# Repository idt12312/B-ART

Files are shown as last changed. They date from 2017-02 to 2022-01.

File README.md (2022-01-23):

# 概要
B-ARTはXbee ZigBeeモジュールみたいにUARTを無線で飛ばすモジュールです。
マイコンのプログラムを追加で書くことなく、UARTのTXとRXだけをつなげるだけでUARTを無線化できます。
無線部分はBLE(Bluetooth Low Energy)で実装をしています。

非常に小さいことが特徴で、**開発中の基板に挿して簡単に使える無線モジュール**をコンセプトに開発をしています。
(現状、秋月で買えるどの無線モジュールよりも小さいはず)

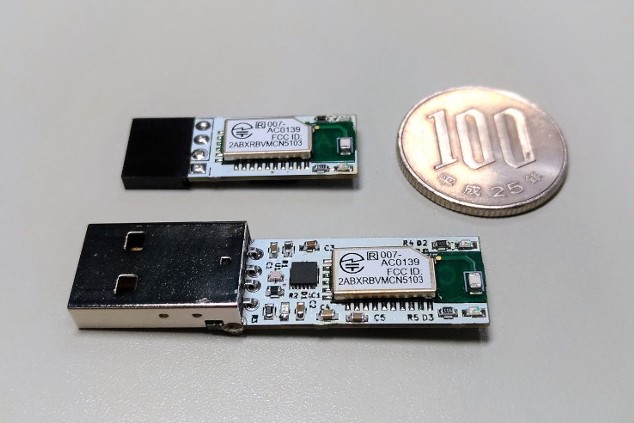
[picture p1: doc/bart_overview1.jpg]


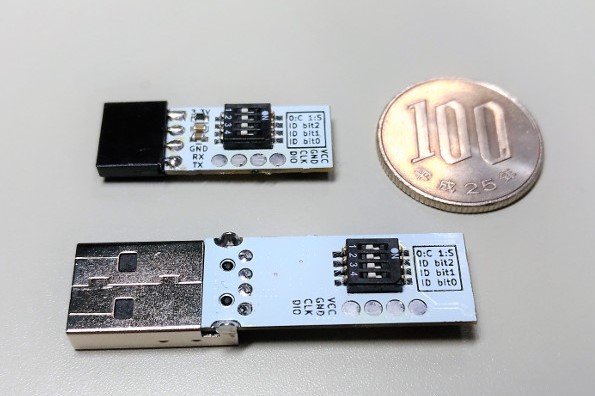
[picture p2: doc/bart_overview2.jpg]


B-ARTにはType-PとType-Uの2種類があり、Type-Pはピンヘッダ、Type-UはUSBコネクタがついています。
Type-Pには4pinのピンヘッダが付いていて、3.3V-GND-TX-RX
の4本を接続するだけで使うことができます。
Type-UにはPCに直接挿せるUSBコネクタと、FTDIのUSB-UART変換IC(FT234XD)が載っています。
FT234XDのおかげでPCにさすとシリアルポートとして認識されるので、
普段シリアルポートを使うときと全く変わることなく使うことができます。

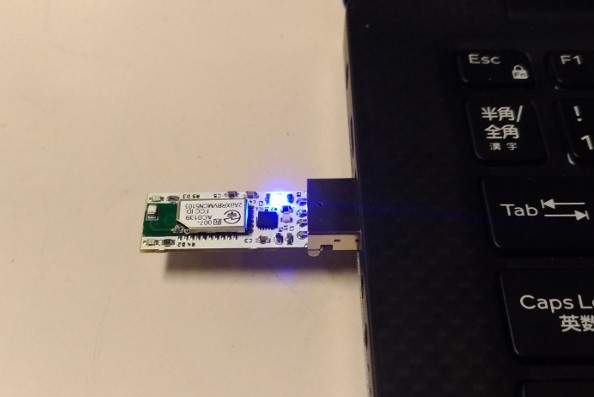
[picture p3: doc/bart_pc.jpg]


B-ARTの裏面にはType-P、Type-UともにDIPスイッチがあり、そこからIDを設定できます。
IDが同じ相手を選択して通信をするので、同じ環境にB-ARTが何組もあってもIDさえ違えば混線が起きないようになっています。

## 使用例
例えば小さい走行ロボットを無線を使ってデバッグする時にB-ARTは役立つでしょう。
走行をさせるときに有線だと線が邪魔になり、Xbeeなどはモジュールが大きすぎて載せられないという状況です。

下の写真は現在制作中のマイクロマウスの機体[MIZUHOv2](http://idken.net/posts/2017-04-01-mizuhov2/)に
B-ART TypePを挿しているところです。

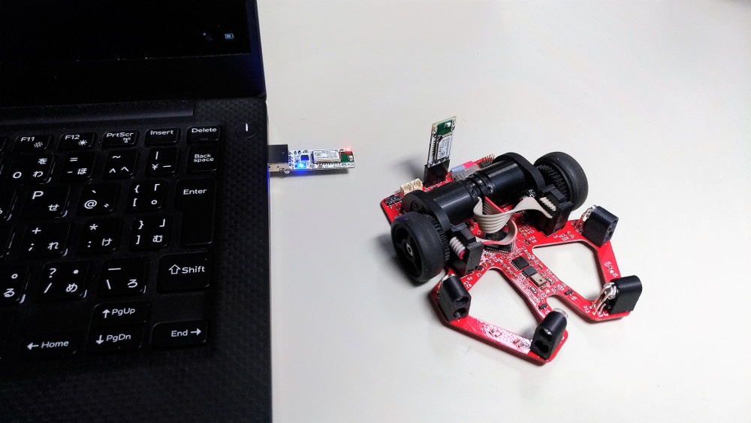
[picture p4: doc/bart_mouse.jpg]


B-ARTは非常に小さく軽いので、マイクロマウスの機体に乗せても走行時にそれほど問題にはなりません。
基板に4pinのコネクタさえつけておけばほしい時にだけB-ARTを挿して使うことができます。

# 使い方

## DIPスイッチの設定

B-ARTのType-PとType-Uの基板の裏にはDIPスイッチが4bit分あり、
1bitはクライアント動作をするかサーバー動作をするか、3bitはIDを意味していています。

| DIPスイッチ | 意味 |
|---|---|
| 1 | 0:client動作  1:server動作 |
| 2 | ID  bit2 |
| 3 | ID  bit1 |
| 4 | ID  bit0 |

B-ARTは通信においてはType-PであるかType-Uであるかは関係なく、
同じIDを持つサーバーとクライアントが1対1で通信できるという仕組みになっています。
なので、同じIDを持っていさえすれば、

* TypeU <-> TypeU
* TypeP <-> TypeP
* TypeU <-> TypeP

の全ての組み合わせで通信が可能です。

## TypePのセットアップ
4pinのピンヘッダ(というよりスルーホール)があり、それぞれのpinは次のような意味を持っています。

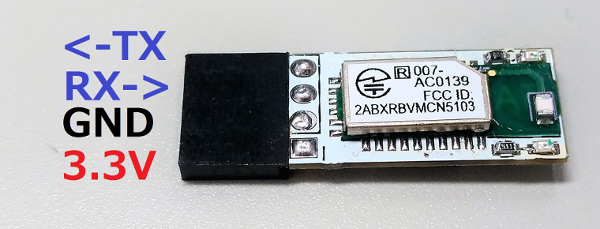
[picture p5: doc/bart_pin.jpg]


B-ARTは最大30mAくらいの電流を必要とするので、それに耐えられるような電源につないでください。

**電源・IOの電圧は3.3Vであることに注意してください**

## TypeUのセットアップ
パソコンのUSBに挿すだけです。

## 電源を入れる
電源を入れると
クライアント動作に設定されているB-ARTは赤色LEDが、
サーバー動作に設定されているB-ARTは緑色のLEDが光ります。

## サーバーとクライアントの接続
サーバー側とクライアント側に同じIDを持たせた状態で電源を入れると自動的に接続されます。
接続された瞬間にB-ARTに乗っている緑と赤の両方のLEDが一瞬点滅します。

一旦切断されても、接続可能な状態になると自動で接続されます。

## データを送受信する
UARTにデータを流すとサーバー側、クライアント側どちらからでももう片方に送信されます。
その際にLEDが点滅するので、LEDを見ることで正常に動作しているかが分かります。

### UARTの通信仕様

以下の設定でのみ動作します。

| パラメータ | 値 |
|---|---|
| Baudrate | 115200bps |
| Data size | 8bit |
| Start bit | 1bit |
| Stop bit | 1bit |
| Parity | なし |
| Flow control | なし |
| 信号レベル | 3.3V |

※UART側からデータを連続して送り続けると、データが欠損する可能性があります。
確実に連続して送信できるのは70byteくらいです。
それ以上のデータが連続する場合は、70byteくらいごとに間隔をあけてください。

# 基板

### TypeP

回路図

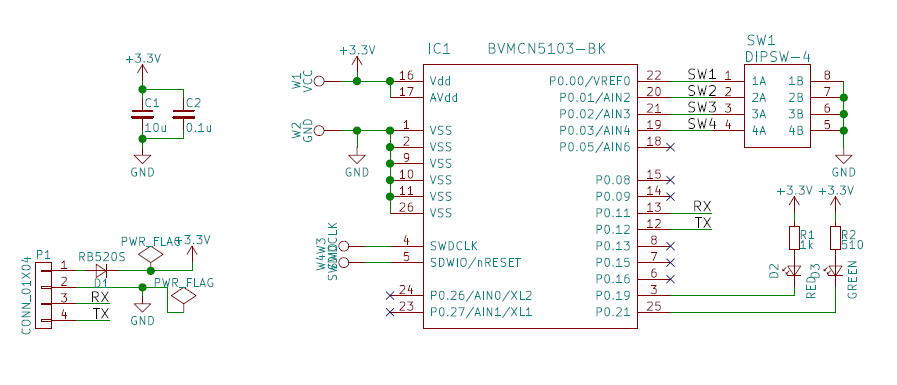
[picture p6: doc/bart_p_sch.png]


アートワーク

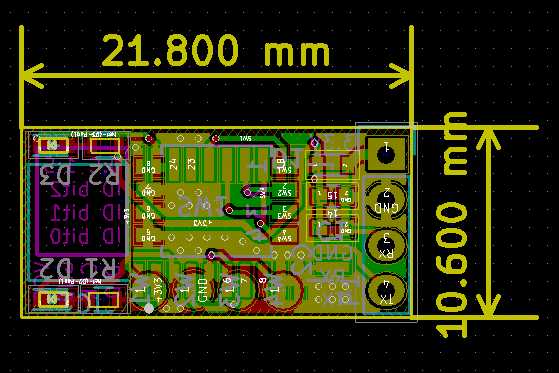
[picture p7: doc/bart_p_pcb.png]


### TypeU

USB周りの回路図

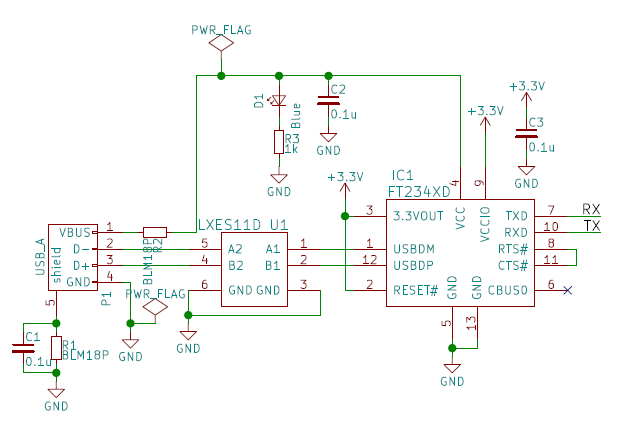
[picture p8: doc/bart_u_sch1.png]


マイコン周りの回路図

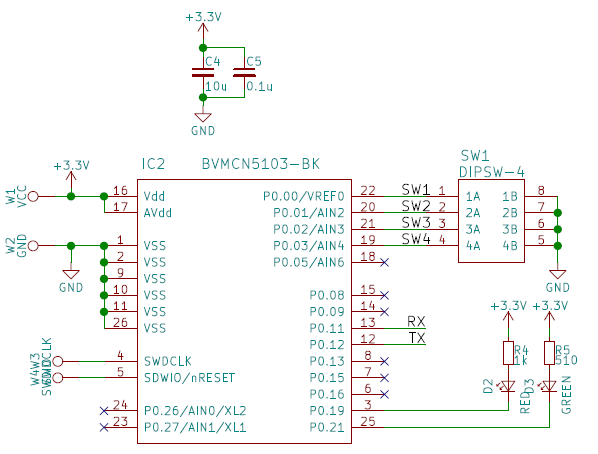
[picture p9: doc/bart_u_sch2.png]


アートワーク

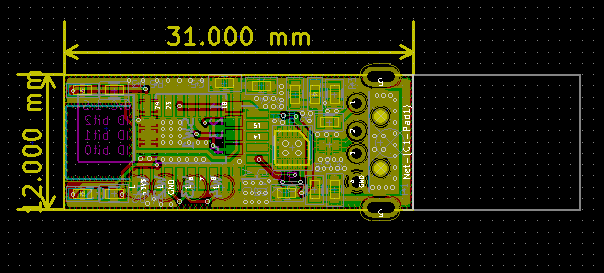
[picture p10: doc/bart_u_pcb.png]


# ファームウェア

## 最新のファームウェアのバイナリ

最新のビルドされたバイナリはbinディレクトリに入っています。

## 開発環境

* [Nordic nRF5 SDK v12.1](https://www.nordicsemi.com/eng/Products/Bluetooth-low-energy/nRF5-SDK)
* Nordic SoftDevice S130
* [Eclipse Juno](https://eclipse.org/)
* [Eclipse CDT](https://eclipse.org/cdt/)
* [GNU ARM Eclipse Plugin](http://gnuarmeclipse.github.io/)
* [gcc-arm-none-eabi-4_9-2015q3](https://launchpad.net/gcc-arm-embedded/4.9/4.9-2015-q3-update)

Eclipseのプロジェクトごとリポジトリにあげてあるので、
きっとEclipseにimportするだけで動かすことができます。

## 動作
起動時にDIPスイッチの状態を読み取って(main.c)、サーバー動作(main_server.c)をするか、
クライアント動作(main_client.c)をするかを決定しています。

BLEの操作はNordicのサンプルにある、NUSを参考にしています。
SDKにあるble_nusとble_nus_cをもとにble_bartsとble_barts_cを書いています。(名前を変えただけ)

### サーバー動作

GATTサーバーとして、次のようなサービスを立てます。

| AttributeType  | Name | Permissions | UUID |
|---|---|---|---|
| Service | BART Service | Read | 20yy0001-DA04-4C71-ADBE-6CA269E7E983 |
| Characteristic | TX | Write | 20yy0002-DA04-4C71-ADBE-6CA269E7E983 |
| Characteristic | RX | Notify | 20yy0003-DA04-4C71-ADBE-6CA269E7E983 |

TXにwriteするとUARTからデータが出力され、
UARTにデータが入るとRXをsubscribeしているデバイスにNotifyします。

UUIDのyyはID(3bit)を16進数に変換したものが入ります。

### クライアント動作
自分と同じIDをもつサーバーを探します。
このとき、サーバーのもつServiceのUUID(上の表のyy)をもとに同じIDのものを検索します。

同じIDのサーバーが見つかったらConnectし、RXのCharactericics(notify)をsubscribeします。

後はUARTからデータが来たらサーバーのRXにwriteをし、サーバーからnotifyが来たらUARTにデータを流します。

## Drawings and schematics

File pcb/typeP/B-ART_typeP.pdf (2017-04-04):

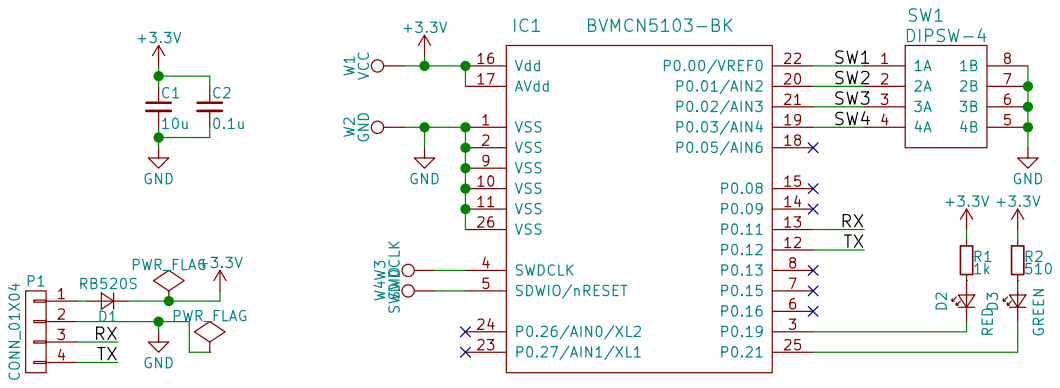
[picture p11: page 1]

SW4 W3 W4 SWDCLK SWDIO W1 VCC W2 GND

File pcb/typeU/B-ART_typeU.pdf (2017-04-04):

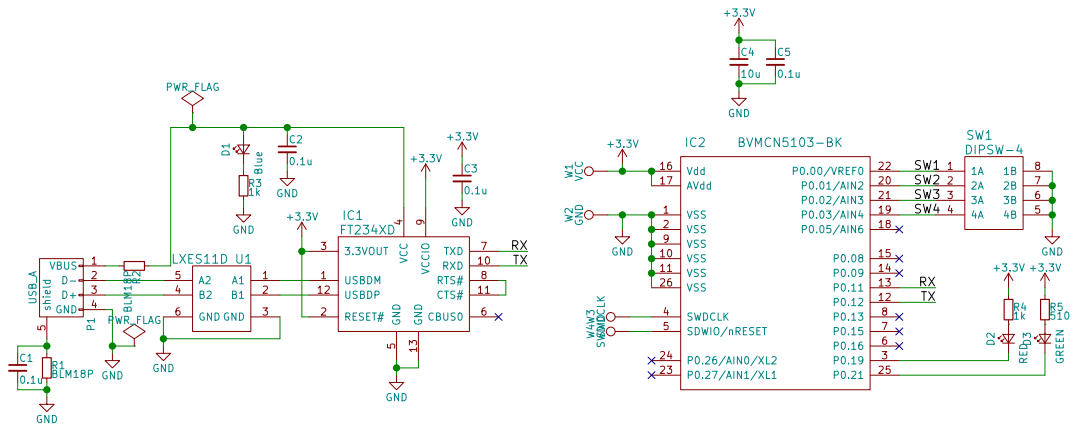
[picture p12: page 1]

9 RXD 10 CTS# 11 USBDP 12 GND 13

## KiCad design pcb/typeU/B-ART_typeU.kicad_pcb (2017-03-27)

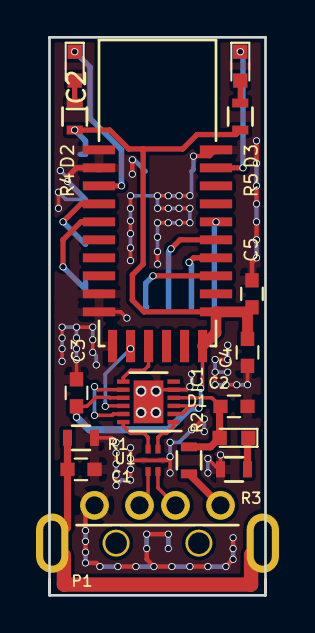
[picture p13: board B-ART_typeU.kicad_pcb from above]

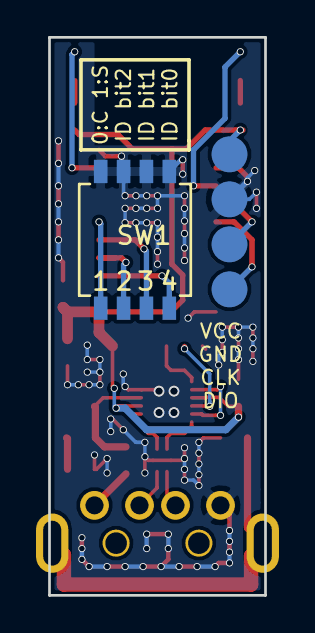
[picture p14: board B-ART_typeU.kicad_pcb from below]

Board: 2 copper layers, 12.0 x 31.0 mm, 22 parts (5 on the bottom side), 23 nets.

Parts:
C1, C2, C3, C5: 0.1u; C_0603
C4: 10u; C_0603
D1: Blue; LED_0603
D2: RED; LED_0603
D3: GREEN; LED_0603
IC1: FT234XD; DFN-12-1EP_3x3mm_Pitch0.45mm
IC2: BVMCN5103-BK
P1: USB_A; USB_A_plug
R1, R2: BLM18P; R_0603
R3, R4: 1k; R_0603
R5: 510; R_0603
SW1: DIPSW-4; DIPSW-4P
U1: LXES11D
W1: VCC; test_th_pad
W2: GND; test_th_pad
W3: SWDCLK; test_th_pad
W4: SWDIO; test_th_pad

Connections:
+3V3: C3.1, C4.1, C5.1, IC1.2, IC1.3, IC1.9, IC2.16, IC2.17, R4.1, R5.1, W1.1
/RX: IC1.7, IC2.13
/SW1: IC2.22, SW1.1
/SW2: IC2.20, SW1.2
/SW3: IC2.21, SW1.3
/SW4: IC2.19, SW1.4
/TX: IC1.10, IC2.12
GND: C1.2, C2.2, C3.2, C4.2, C5.2, IC1.5, IC1.13, IC2.1, IC2.2, IC2.9, IC2.10, IC2.11, IC2.26, P1.4, R1.2, R3.2, SW1.5, SW1.6, SW1.7, SW1.8, U1.3, U1.6, W2.1
unnamed: C1.1, P1.5, R1.1
unnamed: C2.1, D1.2, IC1.4, R2.1
unnamed: D1.1, R3.1
unnamed: D2.1, IC2.3
unnamed: D2.2, R4.2
unnamed: D3.1, IC2.25
unnamed: D3.2, R5.2
unnamed: IC1.1, U1.1
unnamed: IC1.8, IC1.11
unnamed: IC1.12, U1.2
unnamed: IC2.4, W3.1
unnamed: IC2.5, W4.1
unnamed: P1.1, R2.2
unnamed: P1.2, U1.5
unnamed: P1.3, U1.4

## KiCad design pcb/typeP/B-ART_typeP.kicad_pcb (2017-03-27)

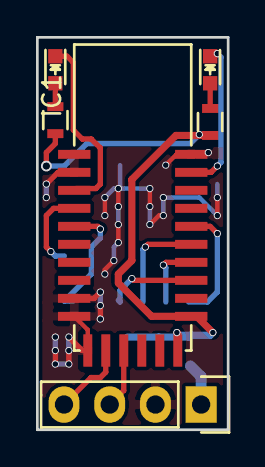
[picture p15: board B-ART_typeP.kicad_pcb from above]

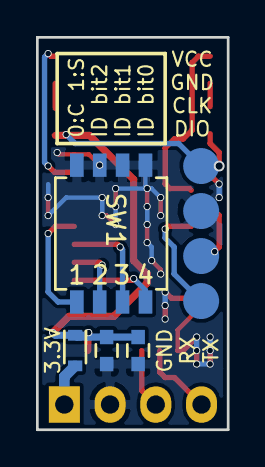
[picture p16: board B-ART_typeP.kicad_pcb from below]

Board: 2 copper layers, 10.6 x 21.8 mm, 14 parts (8 on the bottom side), 15 nets.

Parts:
C1: 10u; C_0603
C2: 0.1u; C_0603
D1: RB520S; D_0603
D2: RED; LED_0603
D3: GREEN; LED_0603
IC1: BVMCN5103-BK
P1: CONN_01X04; Pin_Header_Straight_1x04
R1: 1k; R_0603
R2: 510; R_0603
SW1: DIPSW-4; DIPSW-4P
W1: VCC; test_th_pad
W2: GND; test_th_pad
W3: SWDCLK; test_th_pad
W4: SWDIO; test_th_pad

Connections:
+3V3: C1.1, C2.1, D1.1, IC1.16, IC1.17, R1.1, R2.1, W1.1
/RX: IC1.13, P1.3
/SW1: IC1.22, SW1.1
/SW2: IC1.20, SW1.2
/SW3: IC1.21, SW1.3
/SW4: IC1.19, SW1.4
/TX: IC1.12, P1.4
GND: C1.2, C2.2, IC1.1, IC1.2, IC1.9, IC1.10, IC1.11, IC1.26, P1.2, SW1.5, SW1.6, SW1.7, SW1.8, W2.1
unnamed: D1.2, P1.1
unnamed: D2.1, IC1.3
unnamed: D2.2, R1.2
unnamed: D3.1, IC1.25
unnamed: D3.2, R2.2
unnamed: IC1.4, W3.1
unnamed: IC1.5, W4.1

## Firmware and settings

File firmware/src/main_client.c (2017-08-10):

#include <stdio.h>
#include <stdint.h>
#include <stdbool.h>
#include "nordic_common.h"
#include "app_error.h"
#include "app_uart.h"
#include "ble_db_discovery.h"
#include "app_timer.h"
#include "app_util.h"
#include "app_error.h"
#include "ble.h"
#include "ble_gap.h"
#include "ble_hci.h"
#include "softdevice_handler.h"
#include "ble_advdata.h"
#include "ble_barts_c.h"
#include "app_fifo.h"
#include "nrf_drv_clock.h"

#include "hardware_conf.h"
#include "led.h"


#ifdef DEBUG
#define DBG(...) printf(__VA_ARGS__)
#else
#define DBG(...)
#endif


#define CENTRAL_LINK_COUNT      1                               /**< Number of central links used by the application. When changing this number remember to adjust the RAM settings*/
#define PERIPHERAL_LINK_COUNT   0                               /**< Number of peripheral links used by the application. When changing this number remember to adjust the RAM settings*/

#define BARTS_SERVICE_UUID_TYPE   BLE_UUID_TYPE_VENDOR_BEGIN      /**< UUID type for the Nordic UART Service (vendor specific). */

#define SCAN_INTERVAL           0x00A0                          /**< Determines scan interval in units of 0.625 millisecond. */
#define SCAN_WINDOW             0x0050                          /**< Determines scan window in units of 0.625 millisecond. */
#define SCAN_ACTIVE             1                               /**< If 1, performe active scanning (scan requests). */
#define SCAN_SELECTIVE          0                               /**< If 1, ignore unknown devices (non whitelisted). */
#define SCAN_TIMEOUT            0x0000                          /**< Timout when scanning. 0x0000 disables timeout. */

#define MIN_CONNECTION_INTERVAL MSEC_TO_UNITS(7.5, UNIT_1_25_MS) /**< Determines minimum connection interval in millisecond. */
#define MAX_CONNECTION_INTERVAL MSEC_TO_UNITS(20, UNIT_1_25_MS) /**< Determines maximum connection interval in millisecond. */
#define SLAVE_LATENCY           0                               /**< Determines slave latency in counts of connection events. */
#define SUPERVISION_TIMEOUT     MSEC_TO_UNITS(4000, UNIT_10_MS) /**< Determines supervision time-out in units of 10 millisecond. */

#define UUID16_SIZE             2                               /**< Size of 16 bit UUID */
#define UUID32_SIZE             4                               /**< Size of 32 bit UUID */
#define UUID128_SIZE            16                              /**< Size of 128 bit UUID */

static ble_barts_c_t              m_ble_barts_c;                    /**< Instance of BARTS service. Must be passed to all BARTS_C API calls. */
static ble_db_discovery_t       m_ble_db_discovery;             /**< Instance of database discovery module. Must be passed to all db_discovert API calls */


static const ble_gap_conn_params_t m_connection_param =
{
		(uint16_t)MIN_CONNECTION_INTERVAL,  // Minimum connection
		(uint16_t)MAX_CONNECTION_INTERVAL,  // Maximum connection
		(uint16_t)SLAVE_LATENCY,            // Slave latency
		(uint16_t)SUPERVISION_TIMEOUT       // Supervision time-out
};

static const ble_gap_scan_params_t m_scan_params =
{
		.active      = SCAN_ACTIVE,
		.selective   = SCAN_SELECTIVE,
		.p_whitelist = NULL,
		.interval    = SCAN_INTERVAL,
		.window      = SCAN_WINDOW,
		.timeout     = SCAN_TIMEOUT
};

static const ble_uuid_t m_barts_uuid =
{
		.uuid = BLE_UUID_BARTS_SERVICE,
		.type = BARTS_SERVICE_UUID_TYPE
};


extern uint8_t uart_rcv_buff[UART_RCV_BUF_SIZE];
extern app_fifo_t uart_rcv_fifo;

static uint8_t ble_send_buf[20];
static uint32_t ble_to_send_size;
static bool is_remain_ble_to_send = false;
static bool is_ble_sending = false;
static bool is_ble_send_req = false;


static void transfer_data_from_uart_buf_to_ble()
{
	uint32_t err_code;

	while (1) {
		if (!is_remain_ble_to_send) {
			ble_to_send_size = 20;
			app_fifo_read(&uart_rcv_fifo, ble_send_buf, &ble_to_send_size);
			if (ble_to_send_size == 0) break;
		}

		DBG("[BLE send]");
		for (int i=0;i<ble_to_send_size;i++) {
			DBG("%02x",ble_send_buf[i]);
		}
		DBG("\n");

		err_code = ble_barts_c_send(&m_ble_barts_c, ble_send_buf, ble_to_send_size);

		if (err_code == NRF_SUCCESS) {
			DBG("[BLE send] success\n");
			is_remain_ble_to_send = false;
		}
		else if (err_code == BLE_ERROR_NO_TX_PACKETS || NRF_ERROR_BUSY) {
			DBG("[BLE send] buffer full\n");
			is_remain_ble_to_send = true;
			break;
		}
		else if (err_code != NRF_ERROR_INVALID_STATE) {
			is_remain_ble_to_send = true;
			APP_ERROR_CHECK(err_code);
			break;
		}
	}

}

static void scan_start(void)
{
	uint32_t err_code;

	err_code = sd_ble_gap_scan_start(&m_scan_params);
	APP_ERROR_CHECK(err_code);
}


static void db_disc_handler(ble_db_discovery_evt_t * p_evt)
{
	ble_barts_c_on_db_disc_evt(&m_ble_barts_c, p_evt);
}


void client_uart_event_handle(app_uart_evt_t * p_event)
{
	uint8_t rcv_data;

	switch (p_event->evt_type) {
	case APP_UART_DATA_READY:
		app_uart_get(&rcv_data);

		// 未接続時はデータを無視
		if (m_ble_barts_c.conn_handle == BLE_CONN_HANDLE_INVALID) break;

		app_fifo_put(&uart_rcv_fifo, rcv_data);

		if (!is_ble_sending) {
			is_ble_send_req = true;
		}

		break;

	case APP_UART_COMMUNICATION_ERROR:
		APP_ERROR_HANDLER(p_event->data.error_communication);
		break;

	case APP_UART_FIFO_ERROR:
		APP_ERROR_HANDLER(p_event->data.error_code);
		break;

	default:
		break;
	}
}


static void ble_barts_c_evt_handler(ble_barts_c_t * p_ble_barts_c, const ble_barts_c_evt_t * p_ble_barts_evt)
{
	uint32_t err_code;
	switch (p_ble_barts_evt->evt_type) {
	case BLE_BARTS_C_EVT_DISCOVERY_COMPLETE:
		err_code = ble_barts_c_handles_assign(p_ble_barts_c, p_ble_barts_evt->conn_handle, &p_ble_barts_evt->handles);
		APP_ERROR_CHECK(err_code);

		err_code = ble_barts_c_rx_notif_enable(p_ble_barts_c);
		APP_ERROR_CHECK(err_code);
		DBG("The device has the BART Service\n");
		break;

	case BLE_BARTS_C_EVT_BARTS_RX_EVT:
		DBG("[UART send]");
		led_blink(RX_LED);
		for (uint32_t i = 0; i < p_ble_barts_evt->data_len; i++) {
			DBG("%c", p_ble_barts_evt->p_data[i]);
			while(app_uart_put( p_ble_barts_evt->p_data[i]) != NRF_SUCCESS);
		}
		DBG("\n");
		break;

	case BLE_BARTS_C_EVT_DISCONNECTED:
		DBG("Disconnected\n");
		led_off(TX_LED);
		led_on(RX_LED);
		scan_start();
		break;
	}
}


static bool is_uuid_present(const ble_uuid_t *p_target_uuid,
		const ble_gap_evt_adv_report_t *p_adv_report)
{
	uint32_t err_code;
	uint32_t index = 0;
	uint8_t *p_data = (uint8_t *)p_adv_report->data;
	ble_uuid_t extracted_uuid;

	while (index < p_adv_report->dlen)
	{
		uint8_t field_length = p_data[index];
		uint8_t field_type   = p_data[index+1];

		if ( (field_type == BLE_GAP_AD_TYPE_16BIT_SERVICE_UUID_MORE_AVAILABLE)
				|| (field_type == BLE_GAP_AD_TYPE_16BIT_SERVICE_UUID_COMPLETE)
		)
		{
			for (uint32_t u_index = 0; u_index < (field_length/UUID16_SIZE); u_index++) {
				err_code = sd_ble_uuid_decode(  UUID16_SIZE,
						&p_data[u_index * UUID16_SIZE + index + 2],
						&extracted_uuid);
				if (err_code == NRF_SUCCESS)
				{
					if ((extracted_uuid.uuid == p_target_uuid->uuid)
							&& (extracted_uuid.type == p_target_uuid->type))
					{
						return true;
					}
				}
			}
		}

		else if ( (field_type == BLE_GAP_AD_TYPE_32BIT_SERVICE_UUID_MORE_AVAILABLE)
				|| (field_type == BLE_GAP_AD_TYPE_32BIT_SERVICE_UUID_COMPLETE)
		)
		{
			for (uint32_t u_index = 0; u_index < (field_length/UUID32_SIZE); u_index++) {
				err_code = sd_ble_uuid_decode(UUID16_SIZE,
						&p_data[u_index * UUID32_SIZE + index + 2],
						&extracted_uuid);
				if (err_code == NRF_SUCCESS)
				{
					if ((extracted_uuid.uuid == p_target_uuid->uuid)
							&& (extracted_uuid.type == p_target_uuid->type))
					{
						return true;
					}
				}
			}
		}

		else if ( (field_type == BLE_GAP_AD_TYPE_128BIT_SERVICE_UUID_MORE_AVAILABLE)
				|| (field_type == BLE_GAP_AD_TYPE_128BIT_SERVICE_UUID_COMPLETE)
		)
		{
			err_code = sd_ble_uuid_decode(UUID128_SIZE,
					&p_data[index + 2],
					&extracted_uuid);
			if (err_code == NRF_SUCCESS)
			{
				if ((extracted_uuid.uuid == p_target_uuid->uuid)
						&& (extracted_uuid.type == p_target_uuid->type))
				{
					return true;
				}
			}
		}
		index += field_length + 1;
	}
	return false;
}


static void on_ble_evt(ble_evt_t * p_ble_evt)
{
	uint32_t              err_code;
	uint8_t dummy;
	const ble_gap_evt_t * p_gap_evt = &p_ble_evt->evt.gap_evt;

	switch (p_ble_evt->header.evt_id) {
	case BLE_GAP_EVT_ADV_REPORT:
	{
		DBG("[BLE event] BLE_GAP_EVT_ADV_REPORT\n");

		const ble_gap_evt_adv_report_t * p_adv_report = &p_gap_evt->params.adv_report;

		if (is_uuid_present(&m_barts_uuid, p_adv_report))
		{

			err_code = sd_ble_gap_connect(&p_adv_report->peer_addr,
					&m_scan_params,
					&m_connection_param);

			if (err_code == NRF_SUCCESS)
			{
				// scan is automatically stopped by the connect
				APP_ERROR_CHECK(err_code);
				DBG("Connecting to target %02x%02x%02x%02x%02x%02x\n",
						p_adv_report->peer_addr.addr[0],
						p_adv_report->peer_addr.addr[1],
						p_adv_report->peer_addr.addr[2],
						p_adv_report->peer_addr.addr[3],
						p_adv_report->peer_addr.addr[4],
						p_adv_report->peer_addr.addr[5]
				);
			}
		}
		break;
	}

	case BLE_GAP_EVT_CONNECTED:
		DBG("[BLE event] BLE_GAP_EVT_CONNECTED\n");
		led_blink(TX_LED);
		led_blink(RX_LED);

		// start discovery of services. The BARTS Client waits for a discovery result
		err_code = ble_db_discovery_start(&m_ble_db_discovery, p_ble_evt->evt.gap_evt.conn_handle);
		APP_ERROR_CHECK(err_code);
		break;

	case BLE_GAP_EVT_TIMEOUT:
		DBG("[BLE event] BLE_GAP_EVT_TIMEOUT\n");
		if (p_gap_evt->params.timeout.src == BLE_GAP_TIMEOUT_SRC_SCAN) {
			DBG("Scan timed out\n");
			scan_start();
		}
		else if (p_gap_evt->params.timeout.src == BLE_GAP_TIMEOUT_SRC_CONN) {
			DBG("Connection Request timed out\n");
		}
		break;

	case BLE_GAP_EVT_SEC_PARAMS_REQUEST:
		DBG("[BLE event] BLE_GAP_EVT_SEC_PARAMS_REQUEST\n");
		// Pairing not supported
		err_code = sd_ble_gap_sec_params_reply(p_ble_evt->evt.gap_evt.conn_handle, BLE_GAP_SEC_STATUS_PAIRING_NOT_SUPP, NULL, NULL);
		APP_ERROR_CHECK(err_code);
		break;

	case BLE_GAP_EVT_CONN_PARAM_UPDATE_REQUEST:
		DBG("[BLE event] BLE_GAP_EVT_CONN_PARAM_UPDATE_REQUEST\n");
		// Accepting parameters requested by peer.
		err_code = sd_ble_gap_conn_param_update(p_gap_evt->conn_handle,
				&p_gap_evt->params.conn_param_update_request.conn_params);
		APP_ERROR_CHECK(err_code);
		break;

	case BLE_EVT_TX_COMPLETE:
		led_blink(TX_LED);
		// fifoにデータが残っている
		if (app_fifo_peek(&uart_rcv_fifo, 0, &dummy) == NRF_SUCCESS) {
			transfer_data_from_uart_buf_to_ble();
		}
		else {
			is_ble_sending = false;
		}
		break;

	default:
		break;
	}
}


static void ble_evt_dispatch(ble_evt_t * p_ble_evt)
{
	on_ble_evt(p_ble_evt);
    ble_db_discovery_on_ble_evt(&m_ble_db_discovery, p_ble_evt);
	ble_barts_c_on_ble_evt(&m_ble_barts_c,p_ble_evt);
}


static void ble_stack_init(void)
{
	uint32_t err_code;

	nrf_clock_lf_cfg_t clock_lf_cfg = NRF_CLOCK_LFCLKSRC;

	// Initialize the SoftDevice handler module.
	SOFTDEVICE_HANDLER_INIT(&clock_lf_cfg, NULL);

	ble_enable_params_t ble_enable_params;
	err_code = softdevice_enable_get_default_config(CENTRAL_LINK_COUNT,
			PERIPHERAL_LINK_COUNT,
			&ble_enable_params);
	APP_ERROR_CHECK(err_code);

	//Check the ram settings against the used number of links
	CHECK_RAM_START_ADDR(CENTRAL_LINK_COUNT,PERIPHERAL_LINK_COUNT);

	// 各Bandwidthの許容する接続数を設定
	ble_conn_bw_counts_t bw_counts = {
			.tx_counts = {.high_count=1, .mid_count=0, .low_count=0},
			.rx_counts = {.high_count=1, .mid_count=0, .low_count=0}
	};
	ble_enable_params.common_enable_params.p_conn_bw_counts = &bw_counts;

	// Enable BLE stack.
	err_code = softdevice_enable(&ble_enable_params);
	APP_ERROR_CHECK(err_code);

	// Bandwidthをhihgに設定
	ble_opt_t ble_opt;
	memset(&ble_opt, 0x00, sizeof(ble_opt));
	ble_opt.common_opt.conn_bw.conn_bw.conn_bw_tx = BLE_CONN_BW_HIGH;
	ble_opt.common_opt.conn_bw.conn_bw.conn_bw_rx = BLE_CONN_BW_HIGH;
	ble_opt.common_opt.conn_bw.role = BLE_GAP_ROLE_CENTRAL;

	err_code = sd_ble_opt_set(BLE_COMMON_OPT_CONN_BW, &ble_opt);
	APP_ERROR_CHECK(err_code);

	// Register with the SoftDevice handler module for BLE events.
	err_code = softdevice_ble_evt_handler_set(ble_evt_dispatch);
	APP_ERROR_CHECK(err_code);
}


static void services_init(uint8_t device_id)
{
	uint32_t         err_code;
	ble_barts_c_init_t barts_c_init_t;

	barts_c_init_t.evt_handler = ble_barts_c_evt_handler;

	barts_c_init_t.device_id = device_id;
	DBG("[barts] Device ID : %u\n", barts_c_init_t.device_id);

	err_code = ble_barts_c_init(&m_ble_barts_c, &barts_c_init_t);
	APP_ERROR_CHECK(err_code);
}

static void db_discovery_init(void)
{
	uint32_t err_code = ble_db_discovery_init(db_disc_handler);
	APP_ERROR_CHECK(err_code);
}

static void clock_init()
{
	// 外部のXTALを起動
	uint32_t err_code = nrf_drv_clock_init();
	APP_ERROR_CHECK(err_code);

	nrf_clock_hfclk_t clk_src = nrf_clock_hf_src_get();
	if (clk_src == NRF_CLOCK_HFCLK_LOW_ACCURACY) {
		DBG("NRF_CLOCK_HFCLK_LOW_ACCURACY\n");
	}
	else {
		DBG("NRF_CLOCK_HFCLK_HIGH_ACCURACY\n");
	}

	if (nrf_clock_hf_is_running(NRF_CLOCK_HFCLK_LOW_ACCURACY)) {
		DBG("LOW RUNNING\n");
	}

	if (nrf_clock_hf_is_running(NRF_CLOCK_HFCLK_HIGH_ACCURACY)) {
		DBG("HIGH RUNNING\n");
	}
}

void client_main(uint8_t device_id)
{
	uint32_t err_code;

	app_fifo_init(&uart_rcv_fifo, uart_rcv_buff, UART_RCV_BUF_SIZE);

	db_discovery_init();
	ble_stack_init();
	clock_init();
	services_init(device_id);

	// Start scanning for peripherals and initiate connection
	// with devices that advertise BARTS UUID.
	scan_start();
	DBG("Scan started\n");

	//送信強度を4dB(最大)に設定
	err_code = sd_ble_gap_tx_power_set(4);
	APP_ERROR_CHECK(err_code);

	led_off(TX_LED);
	led_on(RX_LED);

	while (1) {
		if (is_ble_send_req) {
			is_ble_send_req = false;
			transfer_data_from_uart_buf_to_ble();
			is_ble_sending = true;
		}
		uint32_t err_code = sd_app_evt_wait();
		APP_ERROR_CHECK(err_code);
	}
}

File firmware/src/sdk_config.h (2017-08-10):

#ifndef SDK_CONFIG_H
#define SDK_CONFIG_H
// <<< Use Configuration Wizard in Context Menu >>>\n
#ifdef USE_APP_CONFIG
#include "app_config.h"
#endif
// <h> nRF_BLE 

//==========================================================
// <q> BLE_ADVERTISING_ENABLED  - ble_advertising - Advertising module
 

#ifndef BLE_ADVERTISING_ENABLED
#define BLE_ADVERTISING_ENABLED 1
#endif

// <q> BLE_DTM_ENABLED  - ble_dtm - Module for testing RF/PHY using DTM commands
 

#ifndef BLE_DTM_ENABLED
#define BLE_DTM_ENABLED 0
#endif

// <q> BLE_RACP_ENABLED  - ble_racp - Record Access Control Point library
 

#ifndef BLE_RACP_ENABLED
#define BLE_RACP_ENABLED 0
#endif

// <q> NRF_BLE_QWR_ENABLED  - nrf_ble_qwr - Queued writes support module (prepare/execute write)
 

#ifndef NRF_BLE_QWR_ENABLED
#define NRF_BLE_QWR_ENABLED 0
#endif

// <q> PEER_MANAGER_ENABLED  - peer_manager - Peer Manager
 

#ifndef PEER_MANAGER_ENABLED
#define PEER_MANAGER_ENABLED 0
#endif

// </h> 
//==========================================================

// <h> nRF_BLE_Services 

//==========================================================
// <q> BLE_ANCS_C_ENABLED  - ble_ancs_c - Apple Notification Service Client
 

#ifndef BLE_ANCS_C_ENABLED
#define BLE_ANCS_C_ENABLED 0
#endif

// <q> BLE_ANS_C_ENABLED  - ble_ans_c - Alert Notification Service Client
 

#ifndef BLE_ANS_C_ENABLED
#define BLE_ANS_C_ENABLED 0
#endif

// <q> BLE_BAS_C_ENABLED  - ble_bas_c - Battery Service Client
 

#ifndef BLE_BAS_C_ENABLED
#define BLE_BAS_C_ENABLED 0
#endif

// <q> BLE_BAS_ENABLED  - ble_bas - Battery Service
 

#ifndef BLE_BAS_ENABLED
#define BLE_BAS_ENABLED 0
#endif

// <q> BLE_CSCS_ENABLED  - ble_cscs - Cycling Speed and Cadence Service
 

#ifndef BLE_CSCS_ENABLED
#define BLE_CSCS_ENABLED 0
#endif

// <q> BLE_CTS_C_ENABLED  - ble_cts_c - Current Time Service Client
 

#ifndef BLE_CTS_C_ENABLED
#define BLE_CTS_C_ENABLED 0
#endif

// <q> BLE_DIS_ENABLED  - ble_dis - Device Information Service
 

#ifndef BLE_DIS_ENABLED
#define BLE_DIS_ENABLED 0
#endif

// <q> BLE_GLS_ENABLED  - ble_gls - Glucose Service
 

#ifndef BLE_GLS_ENABLED
#define BLE_GLS_ENABLED 0
#endif

// <q> BLE_HIDS_ENABLED  - ble_hids - Human Interface Device Service
 

#ifndef BLE_HIDS_ENABLED
#define BLE_HIDS_ENABLED 0
#endif

// <q> BLE_HRS_C_ENABLED  - ble_hrs_c - Heart Rate Service Client
 

#ifndef BLE_HRS_C_ENABLED
#define BLE_HRS_C_ENABLED 0
#endif

// <q> BLE_HRS_ENABLED  - ble_hrs - Heart Rate Service
 

#ifndef BLE_HRS_ENABLED
#define BLE_HRS_ENABLED 0
#endif

// <q> BLE_HTS_ENABLED  - ble_hts - Health Thermometer Service
 

#ifndef BLE_HTS_ENABLED
#define BLE_HTS_ENABLED 0
#endif

// <q> BLE_IAS_C_ENABLED  - ble_ias_c - Immediate Alert Service Client
 

#ifndef BLE_IAS_C_ENABLED
#define BLE_IAS_C_ENABLED 0
#endif

// <q> BLE_IAS_ENABLED  - ble_ias - Immediate Alert Service
 

#ifndef BLE_IAS_ENABLED
#define BLE_IAS_ENABLED 0
#endif

// <q> BLE_LBS_C_ENABLED  - ble_lbs_c - Nordic LED Button Service Client
 

#ifndef BLE_LBS_C_ENABLED
#define BLE_LBS_C_ENABLED 0
#endif

// <q> BLE_LBS_ENABLED  - ble_lbs - LED Button Service
 

#ifndef BLE_LBS_ENABLED
#define BLE_LBS_ENABLED 0
#endif

// <q> BLE_LLS_ENABLED  - ble_lls - Link Loss Service
 

#ifndef BLE_LLS_ENABLED
#define BLE_LLS_ENABLED 0
#endif

// <q> BLE_NUS_C_ENABLED  - ble_nus_c - Nordic UART Central Service
 

#ifndef BLE_NUS_C_ENABLED
#define BLE_NUS_C_ENABLED 0
#endif

// <q> BLE_NUS_ENABLED  - ble_nus - Nordic UART Service
 

#ifndef BLE_NUS_ENABLED
#define BLE_NUS_ENABLED 0
#endif

// <q> BLE_RSCS_C_ENABLED  - ble_rscs_c - Running Speed and Cadence Client
 

#ifndef BLE_RSCS_C_ENABLED
#define BLE_RSCS_C_ENABLED 0
#endif

// <q> BLE_RSCS_ENABLED  - ble_rscs - Running Speed and Cadence Service
 

#ifndef BLE_RSCS_ENABLED
#define BLE_RSCS_ENABLED 0
#endif

// <q> BLE_TPS_ENABLED  - ble_tps - TX Power Service
 

#ifndef BLE_TPS_ENABLED
#define BLE_TPS_ENABLED 0
#endif

// </h> 
//==========================================================

// <h> nRF_Drivers 

//==========================================================
// <e> ADC_ENABLED - nrf_drv_adc - Driver for ADC peripheral (nRF51)
//==========================================================
#ifndef ADC_ENABLED
#define ADC_ENABLED 0
#endif
#if  ADC_ENABLED
// <o> ADC_CONFIG_IRQ_PRIORITY  - Interrupt priority
 

// <i> Priorities 0,2 (nRF51) and 0,1,4,5 (nRF52) are reserved for SoftDevice
// <0=> 0 (highest) 
// <1=> 1 
// <2=> 2 
// <3=> 3 

#ifndef ADC_CONFIG_IRQ_PRIORITY
#define ADC_CONFIG_IRQ_PRIORITY 3
#endif

#endif //ADC_ENABLED
// </e>

// <e> CLOCK_ENABLED - nrf_drv_clock - CLOCK peripheral driver
//==========================================================
#ifndef CLOCK_ENABLED
#define CLOCK_ENABLED 1
#endif
#if  CLOCK_ENABLED
// <o> CLOCK_CONFIG_XTAL_FREQ  - HF XTAL Frequency
 
// <0=> Default (64 MHz) 
// <255=> Default (16 MHz) 
// <0=> 32 MHz 

#ifndef CLOCK_CONFIG_XTAL_FREQ
#define CLOCK_CONFIG_XTAL_FREQ 255
#endif

// <o> CLOCK_CONFIG_LF_SRC  - LF Clock Source
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

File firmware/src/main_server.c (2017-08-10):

#include <stdint.h>
#include <string.h>
#include "nordic_common.h"
#include "nrf.h"
#include "ble_hci.h"
#include "ble_advdata.h"
#include "ble_advertising.h"
#include "ble_conn_params.h"
#include "softdevice_handler.h"
#include "app_timer.h"
#include "app_uart.h"
#include "app_util_platform.h"
#include "nrf_gpio.h"
#include "nrf_drv_clock.h"
#include "app_fifo.h"

#include "SEGGER_RTT.h"
#include "ble_barts.h"
#include "hardware_conf.h"
#include "led.h"


#ifdef DEBUG
#define DBG(...) printf(__VA_ARGS__)
#else
#define DBG(...)
#endif


#define APP_FEATURE_NOT_SUPPORTED       BLE_GATT_STATUS_ATTERR_APP_BEGIN + 2        /**< Reply when unsupported features are requested. */

#define CENTRAL_LINK_COUNT              0                                           /**< Number of central links used by the application. When changing this number remember to adjust the RAM settings*/
#define PERIPHERAL_LINK_COUNT           1                                           /**< Number of peripheral links used by the application. When changing this number remember to adjust the RAM settings*/

#define DEVICE_NAME                     "BART"                               /**< Name of device. Will be included in the advertising data. */
#define BARTS_SERVICE_UUID_TYPE           BLE_UUID_TYPE_VENDOR_BEGIN                  /**< UUID type for the Nordic UART Service (vendor specific). */

#define APP_ADV_INTERVAL                64                                          /**< The advertising interval (in units of 0.625 ms. This value corresponds to 100 ms). */
#define APP_ADV_TIMEOUT_IN_SECONDS      180                                         	/**< The advertising timeout (in units of seconds). */

#define MIN_CONN_INTERVAL               MSEC_TO_UNITS(7.5, UNIT_1_25_MS)             /**< Minimum acceptable connection interval (7.5 ms), Connection interval uses 1.25 ms units. */
#define MAX_CONN_INTERVAL               MSEC_TO_UNITS(20, UNIT_1_25_MS)             /**< Maximum acceptable connection interval (20 ms), Connection interval uses 1.25 ms units. */
#define SLAVE_LATENCY                   0                                           /**< Slave latency. */
#define CONN_SUP_TIMEOUT                MSEC_TO_UNITS(4000, UNIT_10_MS)             /**< Connection supervisory timeout (4 seconds), Supervision Timeout uses 10 ms units. */
#define FIRST_CONN_PARAMS_UPDATE_DELAY  APP_TIMER_TICKS(5000, APP_TIMER_PRESCALER)  /**< Time from initiating event (connect or start of notification) to first time sd_ble_gap_conn_param_update is called (5 seconds). */
#define NEXT_CONN_PARAMS_UPDATE_DELAY   APP_TIMER_TICKS(30000, APP_TIMER_PRESCALER) /**< Time between each call to sd_ble_gap_conn_param_update after the first call (30 seconds). */
#define MAX_CONN_PARAMS_UPDATE_COUNT    3                                           /**< Number of attempts before giving up the connection parameter negotiation. */

static ble_barts_t					m_barts;
static uint16_t                         m_conn_handle = BLE_CONN_HANDLE_INVALID;    /**< Handle of the current connection. */

static ble_uuid_t                       m_adv_uuids[] = {{.uuid = BLE_UUID_BARTS_SERVICE, .type = BARTS_SERVICE_UUID_TYPE}};


extern uint8_t uart_rcv_buff[UART_RCV_BUF_SIZE];
extern app_fifo_t uart_rcv_fifo;

static uint8_t ble_send_buf[20];
static uint32_t ble_to_send_size;
static bool is_remain_ble_to_send = false;
static bool is_ble_sending = false;
static bool is_ble_send_req = false;

static void transfer_data_from_uart_buf_to_ble()
{
	uint32_t err_code;

	while (1) {
		if (!is_remain_ble_to_send) {
			ble_to_send_size = 20;
			app_fifo_read(&uart_rcv_fifo, ble_send_buf, &ble_to_send_size);
			if (ble_to_send_size == 0) break;
		}

		DBG("[BLE send]");
		for (int i=0;i<ble_to_send_size;i++) {
			DBG("%02x",ble_send_buf[i]);
		}
		DBG("\n");

		err_code = ble_barts_send(&m_barts, ble_send_buf, ble_to_send_size);

		if (err_code == NRF_SUCCESS) {
			DBG("[BLE send] success\n");
			is_remain_ble_to_send = false;
		}
		else if (err_code == BLE_ERROR_NO_TX_PACKETS || NRF_ERROR_BUSY) {
			DBG("[BLE send] buffer full\n");
			is_remain_ble_to_send = true;
			break;
		}
		else if (err_code != NRF_ERROR_INVALID_STATE) {
			is_remain_ble_to_send = true;
			APP_ERROR_CHECK(err_code);
			break;
		}
	}

}

static void gap_params_init(void)
{
	uint32_t                err_code;
	ble_gap_conn_params_t   gap_conn_params;
	ble_gap_conn_sec_mode_t sec_mode;

	BLE_GAP_CONN_SEC_MODE_SET_OPEN(&sec_mode);

	err_code = sd_ble_gap_device_name_set(&sec_mode,
			(const uint8_t *) DEVICE_NAME,
			strlen(DEVICE_NAME));
	APP_ERROR_CHECK(err_code);

	memset(&gap_conn_params, 0, sizeof(gap_conn_params));

	gap_conn_params.min_conn_interval = MIN_CONN_INTERVAL;
	gap_conn_params.max_conn_interval = MAX_CONN_INTERVAL;
	gap_conn_params.slave_latency     = SLAVE_LATENCY;
	gap_conn_params.conn_sup_timeout  = CONN_SUP_TIMEOUT;

	err_code = sd_ble_gap_ppcp_set(&gap_conn_params);
	APP_ERROR_CHECK(err_code);
}


static void barts_data_handler(ble_barts_t * p_barts, uint8_t * p_data, uint16_t length)
{
	DBG("[UART send]");
	for (uint32_t i = 0; i < length; i++) {
		while (app_uart_put(p_data[i]) != NRF_SUCCESS);
		DBG("%c",p_data[i]);
	}
	DBG("\n");
}


static void services_init(uint8_t device_id)
{
	uint32_t       err_code;
	ble_barts_init_t barts_init;

	memset(&barts_init, 0, sizeof(barts_init));

	barts_init.data_handler = barts_data_handler;

	// device id の設定
	barts_init.device_id = device_id;
	DBG("[barts] Device ID : %u\n", barts_init.device_id);

	err_code = ble_barts_init(&m_barts, &barts_init);
	APP_ERROR_CHECK(err_code);
}


static void on_conn_params_evt(ble_conn_params_evt_t * p_evt)
{
	uint32_t err_code;

	if (p_evt->evt_type == BLE_CONN_PARAMS_EVT_FAILED) {
		err_code = sd_ble_gap_disconnect(m_conn_handle, BLE_HCI_CONN_INTERVAL_UNACCEPTABLE);
		APP_ERROR_CHECK(err_code);
	}
}


static void conn_params_error_handler(uint32_t nrf_error)
{
	APP_ERROR_HANDLER(nrf_error);
}


static void conn_params_init(void)
{
	uint32_t               err_code;
	ble_conn_params_init_t cp_init;

	memset(&cp_init, 0, sizeof(cp_init));

	cp_init.p_conn_params                  = NULL;
	cp_init.first_conn_params_update_delay = FIRST_CONN_PARAMS_UPDATE_DELAY;
	cp_init.next_conn_params_update_delay  = NEXT_CONN_PARAMS_UPDATE_DELAY;
	cp_init.max_conn_params_update_count   = MAX_CONN_PARAMS_UPDATE_COUNT;
	cp_init.start_on_notify_cccd_handle    = BLE_GATT_HANDLE_INVALID;
	cp_init.disconnect_on_fail             = false;
	cp_init.evt_handler                    = on_conn_params_evt;
	cp_init.error_handler                  = conn_params_error_handler;

	err_code = ble_conn_params_init(&cp_init);
	APP_ERROR_CHECK(err_code);
}
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

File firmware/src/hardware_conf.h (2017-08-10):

/*
 * hardware_conf.h
 *
 *  Created on: 2016/11/29
 *      Author: idt12312
 */

#ifndef SRC_HARDWARE_CONF_H_
#define SRC_HARDWARE_CONF_H_

#define TX_LED_PIN_NUMBER	21
#define RX_LED_PIN_NUMBER	19

#define	TX_PIN_NUMBER	12
#define	RX_PIN_NUMBER	11
#define	RTS_PIN_NUMBER	0
#define	CTS_PIN_NUMBER	0

#define DEVICEID_BIT0_PIN_NUMBER 3
#define DEVICEID_BIT1_PIN_NUMBER 2
#define DEVICEID_BIT2_PIN_NUMBER 1
#define DEVICE_MODE_PIN_NUMBER 0


#define UART_TX_BUF_SIZE                128                                         /**< UART TX buffer size. */
#define UART_RX_BUF_SIZE                64                                         /**< UART RX buffer size. */
#define UART_RCV_BUF_SIZE				128

/**< Value of the RTC1 PRESCALER register. */
#define APP_TIMER_PRESCALER 0

#define APP_TIMER_OP_QUEUE_SIZE         5                                           /**< Size of timer operation queues. */


#define NRF_CLOCK_LFCLKSRC      {.source        = NRF_CLOCK_LF_SRC_RC,            \
                                 .rc_ctiv       = 32,                                \
                                 .rc_temp_ctiv  = 1,                                \
                                 .xtal_accuracy = NRF_CLOCK_LF_XTAL_ACCURACY_250_PPM}



#endif /* SRC_HARDWARE_CONF_H_ */

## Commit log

2016-11-27 基板データを作成
    [uart2ble_bridge.kicad_pcb, uart2ble_bridge.sch]
2016-11-28 nordic SDK v12.1 + Eclipse で開発環境を構築 uart2bleのサービスを実装(nusとほとんど同じ)
2016-11-28 図面のプロパティを設定
    [uart2ble_bridge.kicad_pcb, uart2ble_bridge.sch]
2016-11-29 LEDを二つともマイコンから操作できるように変更
    [uart2ble_bridge.kicad_pcb, uart2ble_bridge.sch]
2016-11-29 LEDの操作を追加
2016-12-27 firm 裏面のジャンパーピンを参照してdevice idを決定する部分を実装
2016-12-27 firm LEDの光りかたを微調整
2017-01-15 アドバタイズに含めるserviceのUUIDを修正
2017-01-25 クライアントの処理を追加
    NUS_Cのサンプルを模倣
2017-01-29 クライアント側でBLEのイベントをdb_discoveryに通知し忘れていたので修正
2017-01-29 送信強度を4dB(最大)に設定
2017-01-29 LED, デバッグ出力周りを修正
2017-02-09 USB付き基板を追加 + 以前の基板も修正
    [uart2ble_bridge.kicad_pcb, uart2ble_bridge.sch, uart2ble_bridge_usb.kicad_pcb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]
2017-02-11 新しい基板に合わせてIOピン周りを修正
2017-03-08 firm_server: アドバタイズに乗せるServiceのUUIDの設定が間違っていたので修正
2017-03-08 firm_server: アドバタイズがタイムアウトしても再度アドバタイズを出すように修正
2017-03-09 firm: BLEが未接続時にはUARTのデータを無視する処理を追加
2017-03-27 firm: Eclipseのプロジェクト名を変更
    bleのサービス名もB-ARTに変更
2017-03-27 pcb: KiCadのプロジェクト名を変更
    [B-ART_typeP.kicad_pcb, B-ART_typeP.sch, B-ART_typeU.kicad_pcb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]
2017-04-01 ライブラリが除外されていたので追加
2017-04-01 回路図を成形 & 回路図pdfを追加
    [B-ART_typeP.sch, B-ART_typeU.sch]
2017-04-04 ドキュメントを追加
2017-04-04 画像へのリンクを修正
2017-04-04 READMEを修正
2017-04-04 READMEの画像をサイズを縮小
2017-08-08 firm: BandwidthとConnection Intervalを調整
2017-08-10 firm: クロックの設定を修正
    HFCLKには外部のXTALを使う設定に
2017-08-10 Connection IntervalごとにUARTから受信したデータを送るように変更
    ・UARTの受信イベントで得たデータはいったんFIFOに貯めておき、BLEのパケットが送信されるごとに送れるだけ送る実装に変更
    ・UARTの割り込み優先度を上げた
    ・115200bpsで80byteくらいまでしか連続で送れない
2017-08-10 firm: ファームのバイナリをbinに追加
2017-08-11 READMEを更新
